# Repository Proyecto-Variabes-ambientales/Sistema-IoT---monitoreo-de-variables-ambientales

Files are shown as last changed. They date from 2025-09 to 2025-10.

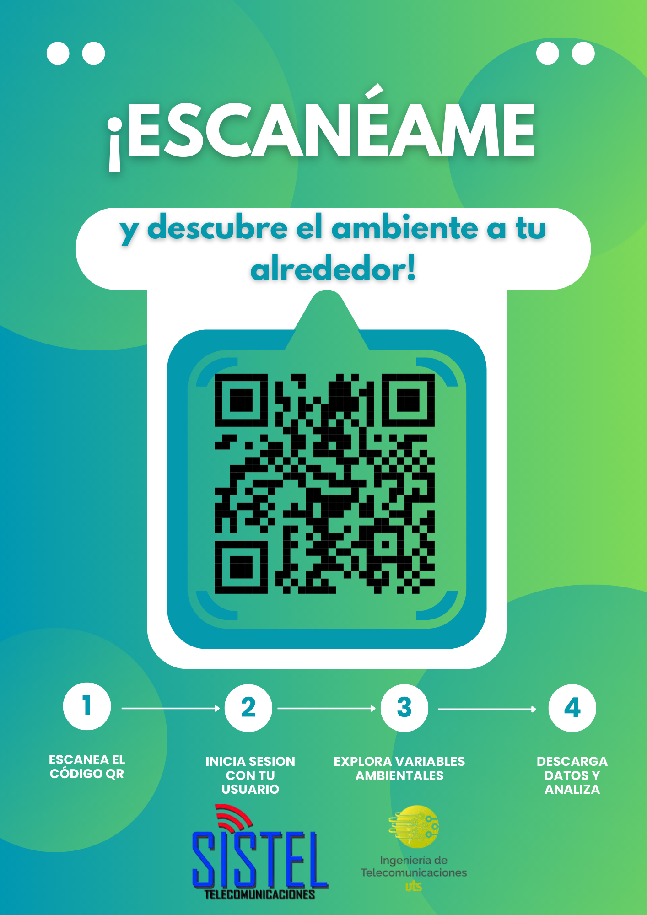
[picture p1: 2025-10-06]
Anexo F -Ficha publicitaria.png

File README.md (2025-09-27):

# Sistema-IoT---monitoreo-de-variables-ambientales
Panel web y firmware para un sistema de monitoreo de calidad del aire basado en Wemos D1 R32, con el uso de los sensores SCD40 (CO2, temperatura, humedad) y MPM10-AG (PM1.0/PM2.5/PM10). Los datos se almacenan en Firebase Realtime Database y se visualizan en un dashboard responsivo con Chart.js filtros por rango, estado y exportación a CSV

- Envío periódico de lecturas(CO2, T, RH, PM1/2.5/10).
- Gráficas en tiempo real, promedio, máx/mín, comparacion de días y fuera de rango.
- Exportación de datos a CSV por rango de fechas.
- Autentication con Firebase Auth.
- Panel admin: registro de boards con PIN por correo.
- Limites configurables y auto-referesco

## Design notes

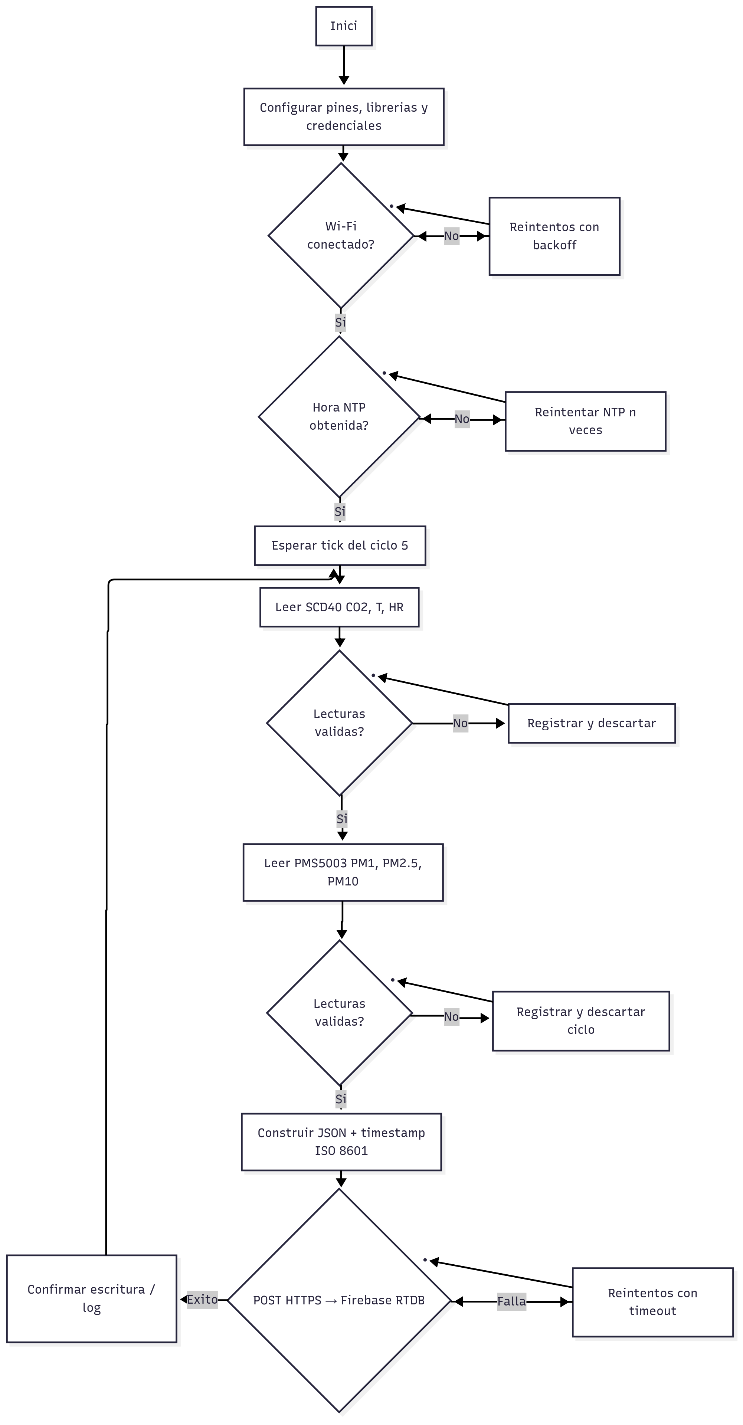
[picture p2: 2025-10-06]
Anexo E - Diagrama de flujo- Firmware.png

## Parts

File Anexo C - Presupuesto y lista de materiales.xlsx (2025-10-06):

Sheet: Materiales y precios
Cantidad | Descripción | Observación | Precio
1 | Wemos D1 R32 | Wi-Fi, 4MB flash | $45000.00
1 | SCD40 (sensor) | C02, T, RH )I2C | $95000.00
1 | MPM10-AG | PM1/2.5/10 (UART) | $52000.00
1 | Fuente 12V DC 3A | Con toma a red | $22000.00
1 | Power Bank | Bateria de respaldo | $90000.00
1 | Caja metalica | Con malla e impresiones 3D | $100000.00
8 | Cables jumper | Conectividad limpia y segura | $8500.00
4 | Tornilleria | fijacion del equipo | $10000.00
 |  |  | $422500.00

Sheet: Check-list
Checklist de instalación |  | X
Ubicación y montaje | Altura 1,7–2,0 m; zona de paso ventilada; sombra indirecta.
 | Caja fijada y nivelada; orificios de ventilación despejados y con malla.
 | Sin fuentes puntuales de calor/CO₂ a < 2 m (extractores, escapes, hornos).
Eléctrico y conexiones | Fuente 12 V ≥ 3 A; polaridad verificada.
 | Conectores bien conectados; cableado sin peladuras.
 | PMS (5 V) y SCD40 (3.3 V) con masa común.
Firmware y red | BOARD_ID programado; credenciales Wi-Fi cargadas.
 | Sincronización NTP OK; zona horaria verificada.
 | Conexión a Firebase: OK (paquetes en <5 min).
Verificación funcional (15–30 min) | Lecturas CO₂/T°/RH/PM aparecen en el dashboard.
 | Gráficas en modo tiempo real actualizan cada minuto.
 | Botones Rango/Prom/Max-Min/Comparar/Out of Range/Reset operativos.

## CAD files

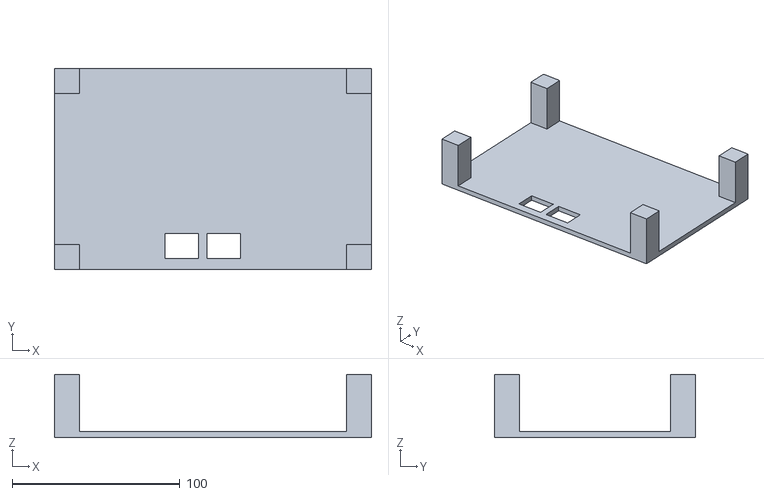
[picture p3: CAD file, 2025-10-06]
Anexo H - Diseños 3D/doble altura para bateria.stl
189.0 x 120.0 x 37.7

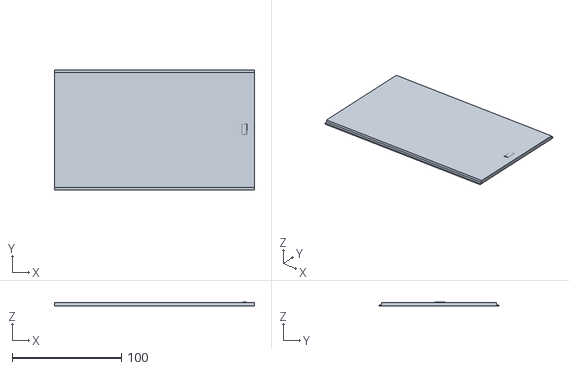
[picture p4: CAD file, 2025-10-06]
Anexo H - Diseños 3D/tapa caja principal.stl
182.7 x 109.9 x 4.03

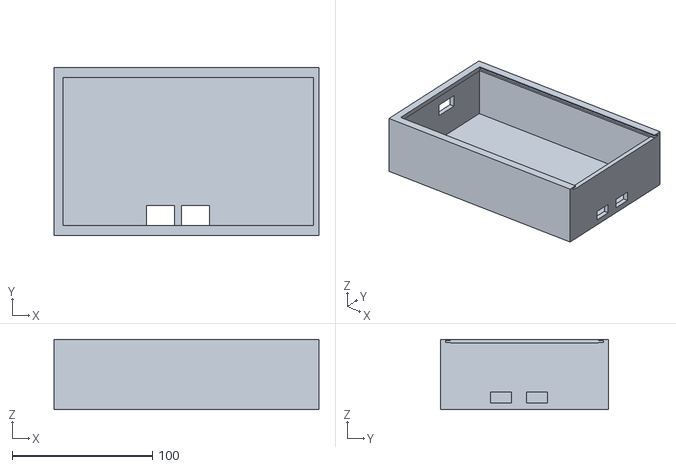
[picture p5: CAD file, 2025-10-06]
Anexo H - Diseños 3D/caja principal.stl
189.0 x 120.0 x 50.2

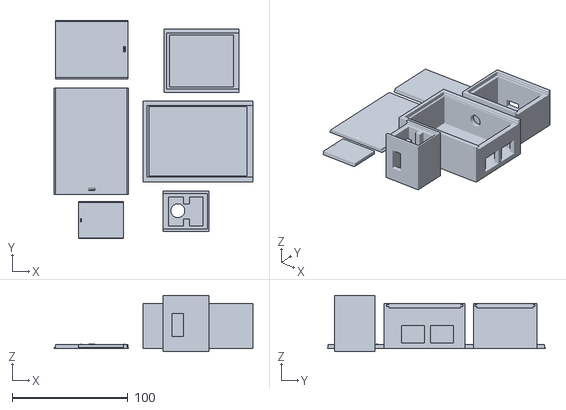
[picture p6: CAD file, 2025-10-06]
Anexo H - Diseños 3D/todas las cajas para los elementos electronicos.stl
172.0 x 188.8 x 48.5

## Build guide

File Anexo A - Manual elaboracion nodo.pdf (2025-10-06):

# Manual de construcción y

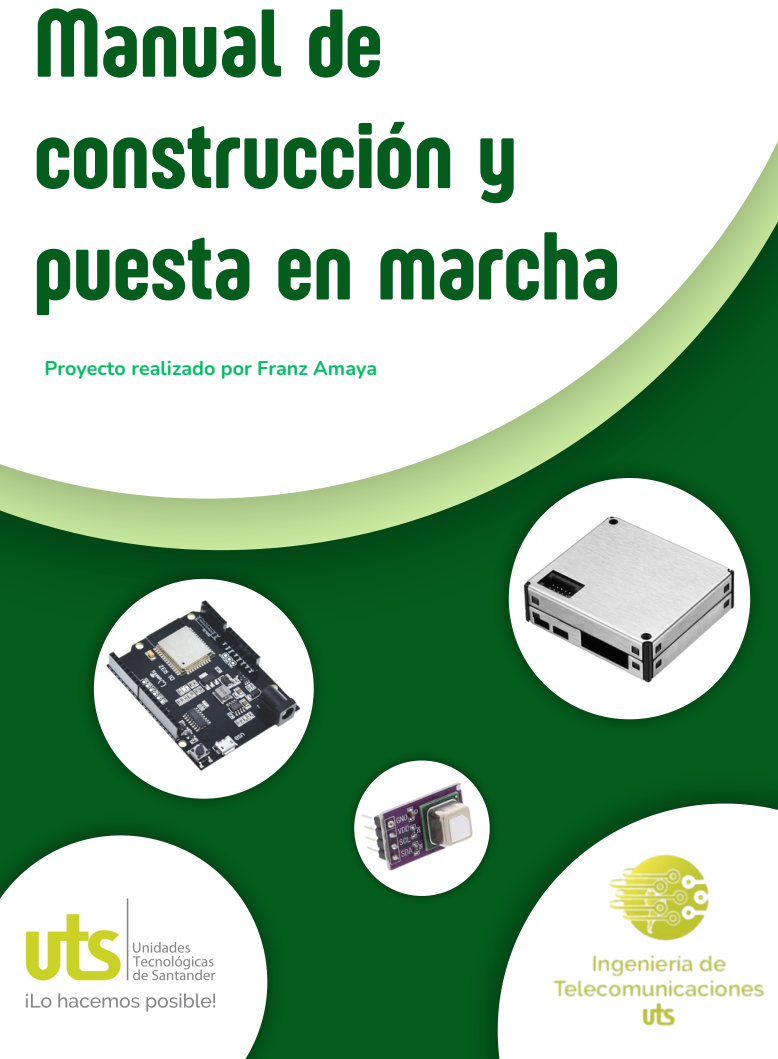
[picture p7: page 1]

puesta en marcha

Proyecto realizado por Franz Amaya

# MANUAL DE INSTRUCCIONES

Sistema IoT para el monitoreo de variables ambientales (ESP32 + SCD40 + PM2.5)

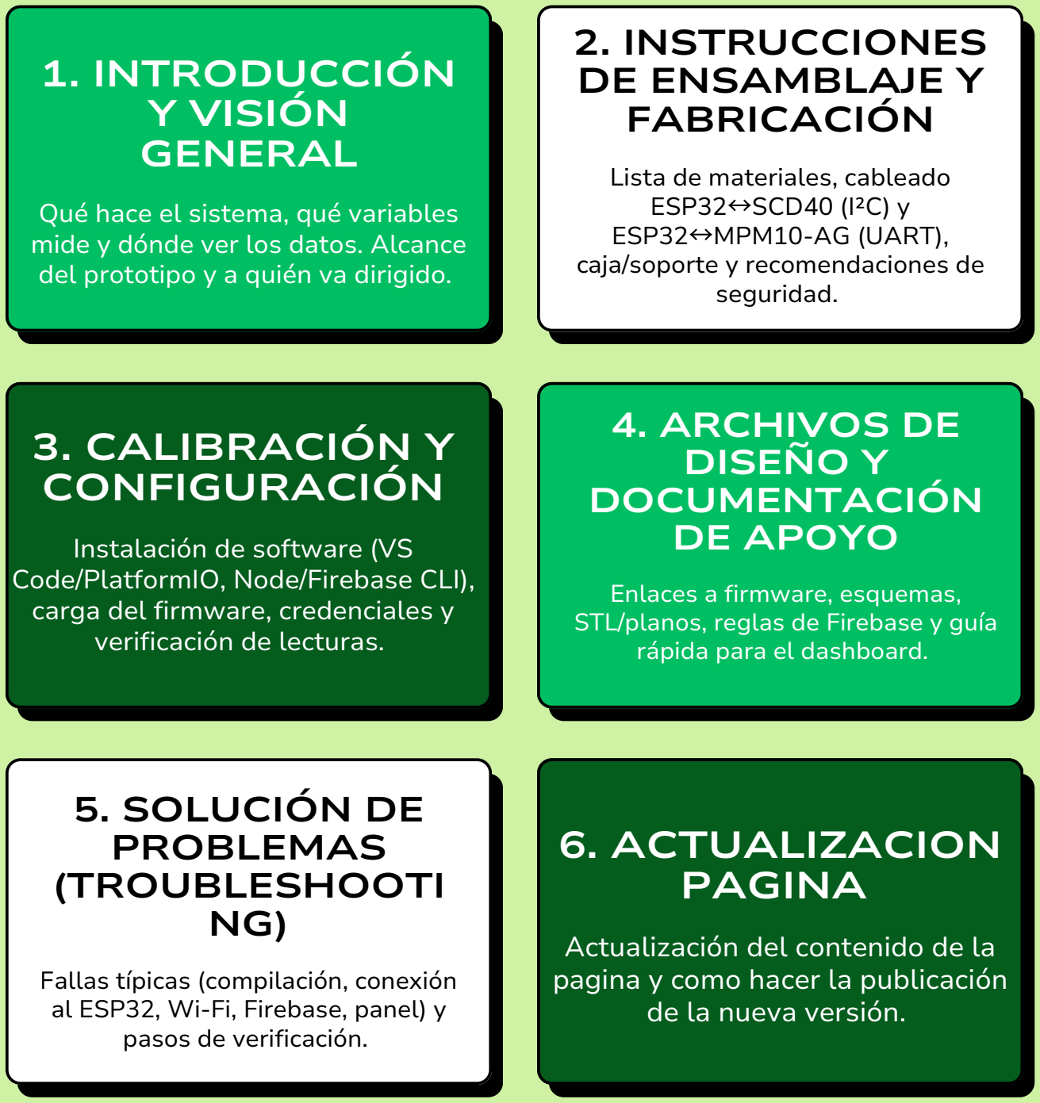
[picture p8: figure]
1. INTRODUCCIÓN Y VISIÓN GENERAL; Qué hace el sistema, qué variables mide y dónde ver los datos. Alcance del prototipo y a quién va dirigido.; 3. CALIBRACIÓN Y CONFIGURACIÓN; Instalación de software (VS Code/PlatformIO, Node/Firebase CLI), carga del firmware, credenciales y verificación de lecturas.; 5. SOLUCIÓN DE PROBLEMAS (TROUBLESHOOTI NG); Fallas típicas (compilación, conexión al ESP32, Wi-Fi, Firebase, panel) y pasos de verificación.; 2. INSTRUCCIONES DE ENSAMBLAJE Y FABRICACIÓN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

Proyecto académico – Programa Ingeniería de Telecomunicaciones – UTS.

# INSTRUCCIONES

### 1. Introducción y Visión General

### PROPÓSITO DEL MANUAL

Este manual explica paso a paso cómo reproducir el prototipo de monitoreo ambiental basado en una Wemos D1 R32 (ESP32), un sensor SCD40 (CO₂, temperatura y humedad) y un sensor láser de partículas PM2.5 (MPM10-AG). Encontrarás la lista completa de materiales, el ensamble eléctrico y mecánico, la carga del firmware, el despliegue del panel web y pruebas de verificación. La idea es que puedas copiar el proyecto de principio a fin y adaptarlo a tu contexto.

### DESCRIPCIÓN DEL PROTOTIPO

El sistema mide CO₂ (ppm), temperatura (°C), humedad relativa (%) y PM2.5 (µg/m³), sube los datos cada 5 min a Firebase Realtime Database y los muestra en un panel web con pestañas por variable, comparación por días, promedio, máximos/mínimos y aviso por colores (verde/amarillo/rojo). Se pensó para su instalación en exteriores (plazoleta UTS) con una caja protectora ventilada.

# INSTRUCCIONES

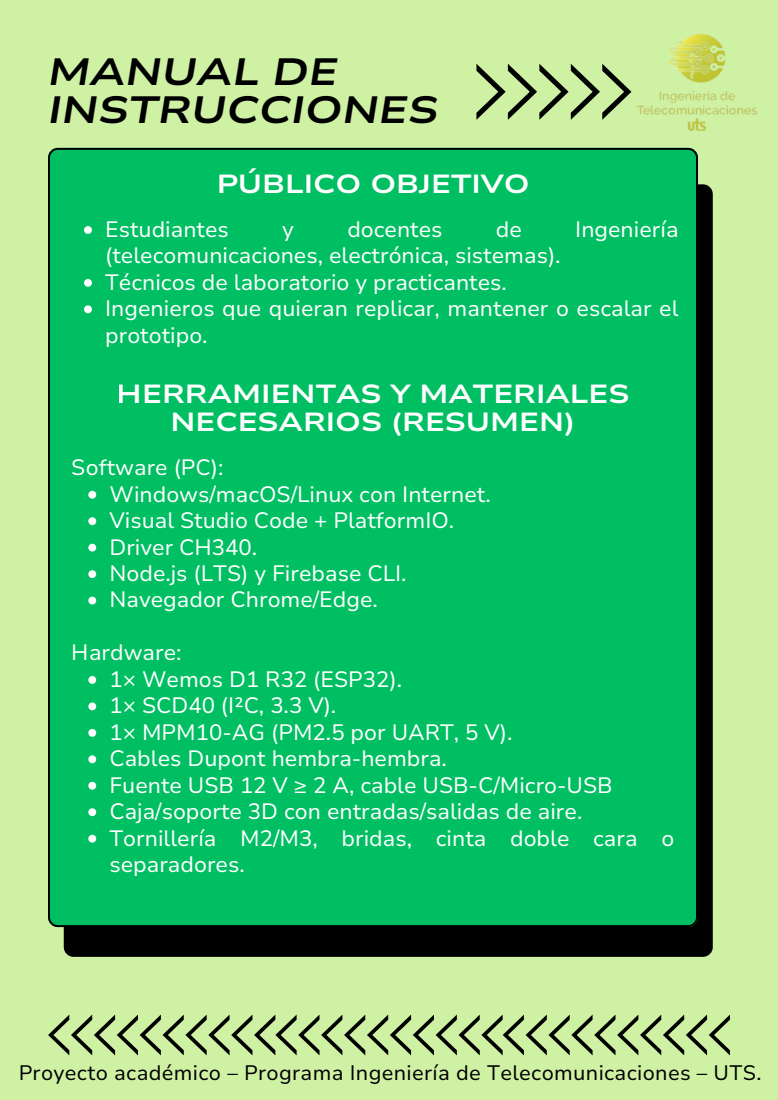
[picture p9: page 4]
PÚBLICO OBJETIVO; Estudiantes; docentes; Ingeniería

(telecomunicaciones, electrónica, sistemas).
Técnicos de laboratorio y practicantes.
Ingenieros que quieran replicar, mantener o escalar el
prototipo.
HERRAMIENTAS Y MATERIALES
NECESARIOS (RESUMEN)

Software (PC):
Windows/macOS/Linux con Internet.
Visual Studio Code + PlatformIO.
Driver CH340.
Node.js (LTS) y Firebase CLI.
Navegador Chrome/Edge.
Hardware:
1× Wemos D1 R32 (ESP32).
1× SCD40 (I²C, 3.3 V).
1× MPM10-AG (PM2.5 por UART, 5 V).
Cables Dupont hembra-hembra.
Fuente USB 12 V ≥ 2 A, cable USB-C/Micro-USB
Caja/soporte 3D con entradas/salidas de aire.
Tornillería M2/M3, bridas, cinta doble cara o
separadores.

Ítem | Cant. | Especificación
Wemos D1 R32 (ESP32) | 1 | MCU Wi-Fi/BLE a 3.3 V; USB, GPIO21=SDA, GPIO22=SCL, UART2=IO16/IO17
Sensor SCD40 | 1 | CO₂, T, RH; VCC=3.3 V, I²C (SDA/SCL)
Sensor PM2.5 MPM10-AG | 1 | Láser; VCC=5 V, UART (TX/RX)
Cables Dupont | 20+ | Hembra-hembra, 10–15 cm
Fuente USB 5 V ≥ 1A | 1 | Alimentación del ESP32
Caja/soporte | 1 | Impresa en 3D o metálica con ventilación
Tornillos/separadores | Var | M2/M3, nylon o metal
Filtros anti-insectos | 2 | Tela/fieltro respirable
PC con VSCode | 1 | PlatformIO, Firebase CLI

# INSTRUCCIONES

### 2. Instrucciones de ensamblaje y fabricación

### 2.1 LISTA DE MATERIALES (BOM)

# INSTRUCCIONES

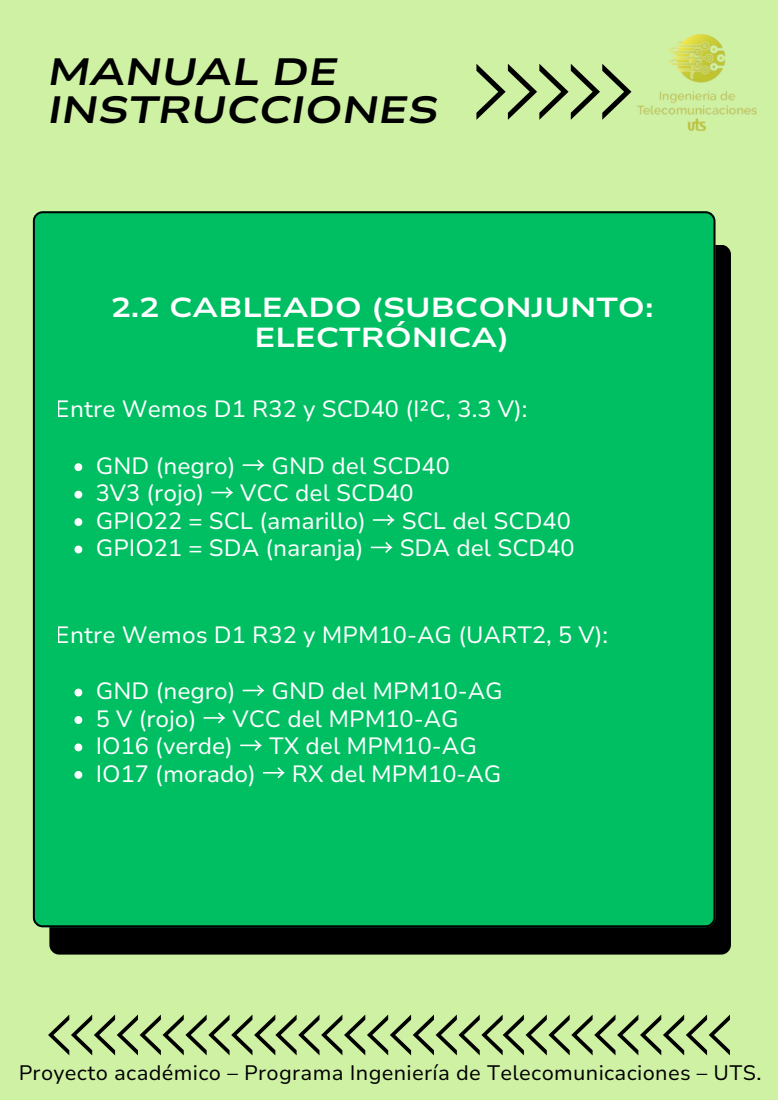
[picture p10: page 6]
2.2 CABLEADO (SUBCONJUNTO: ELECTRÓNICA)

Entre Wemos D1 R32 y SCD40 (I²C, 3.3 V):
GND (negro) → GND del SCD40
3V3 (rojo) → VCC del SCD40
GPIO22 = SCL (amarillo) → SCL del SCD40
GPIO21 = SDA (naranja) → SDA del SCD40

Entre Wemos D1 R32 y MPM10-AG (UART2, 5 V):
GND (negro) → GND del MPM10-AG
5 V (rojo) → VCC del MPM10-AG
IO16 (verde) → TX del MPM10-AG
IO17 (morado) → RX del MPM10-AG

# INSTRUCCIONES

## 2.3 CAJA/SOPORTE (SUBCONJUNTO: MECÁNICA)

Ubica el SCD40 en un compartimento ventilado y sombreado, con entrada superior tipo visera (evita radiación directa).

El PM2.5 necesita dos conductos: entrada y salida separados y alineados con sus puertos.

Deja pasajes de aire de 6–10 mm para SCD40 y conductos dedicados para el PM (30–40 mm de largo).

Mantén cables ordenados con bridas y deja juego para vibración térmica.

Considera tornillos de fijación y burletes de goma para vibración/estanqueidad.

# INSTRUCCIONES

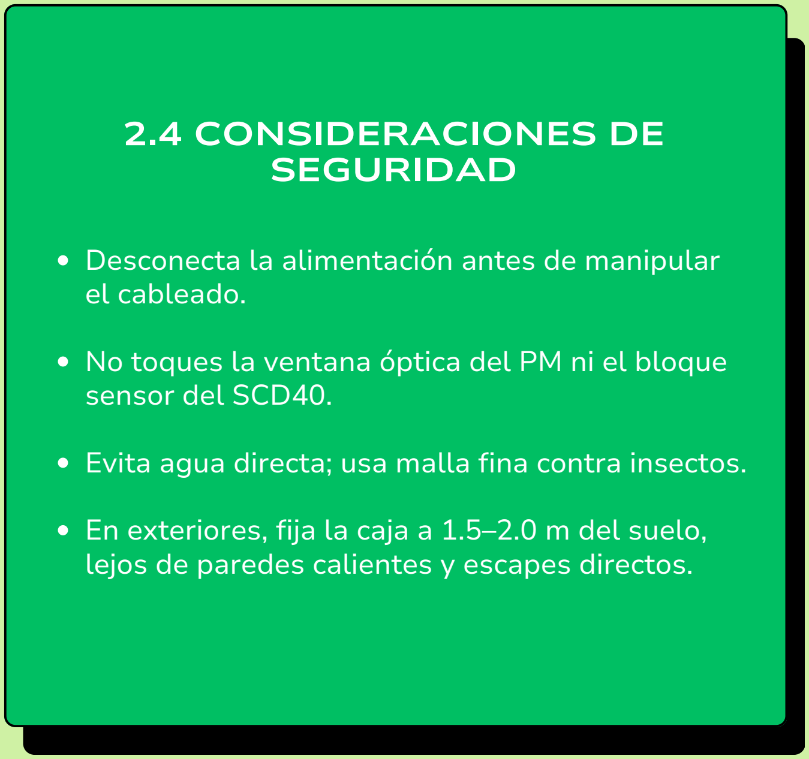
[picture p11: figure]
2.4 CONSIDERACIONES DE SEGURIDAD; el cableado.; sensor del SCD40.

Desconecta la alimentación antes de manipular

No toques la ventana óptica del PM ni el bloque

Evita agua directa; usa malla fina contra insectos.

En exteriores, fija la caja a 1.5–2.0 m del suelo, lejos de paredes calientes y escapes directos.

# INSTRUCCIONES

### 3. Calibración, software y configuración

### 3.1 INSTALACIÓN DE SOFTWARE

(PC)
1.Instala VS Code.
2.Abre VS Code → Extensions → instala PlatformIO IDE. 3.Instala driver USB (CH340).
4.Instala Node.js (LTS).
5.Abre una terminal y ejecuta:
npm i -g firebase-tools → instala Firebase CLI. firebase login → inicia sesión en tu cuenta.

### 3.2 PROYECTO PLATFORMIO

El sistema mide CO₂ (ppm), temperatura (°C), humedad relativa (%) y PM2.5 (µg/m³), sube los datos cada 5 min a Firebase Realtime Database y los muestra en un panel web con pestañas por variable, comparación por días, promedio, máximos/mínimos y aviso por colores (verde/amarillo/rojo). Se pensó para su instalación en exteriores (plazoleta UTS) con una caja protectora ventilada.

### 3.3 CODIGOS Y REGLAS

Para acceder a los códigos ingresa al siguiente GitHub y sigue el paso a paso que se describe en el README y demás archivos.

# INSTRUCCIONES

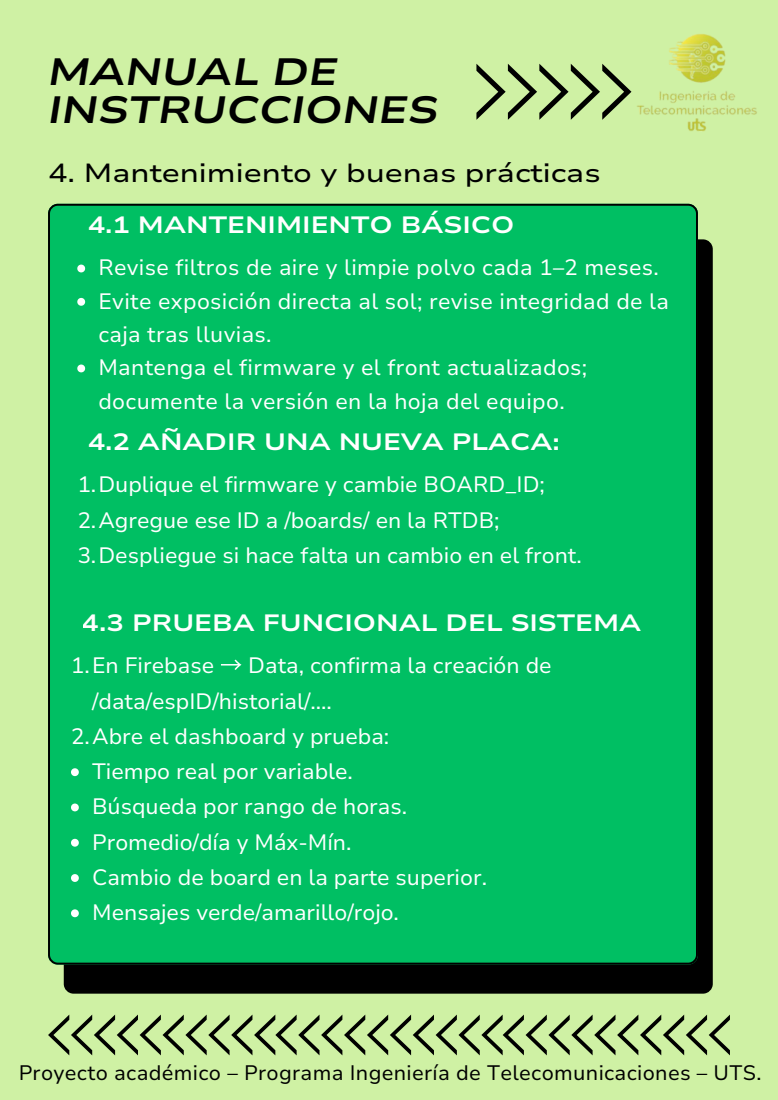
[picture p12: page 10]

4. Mantenimiento y buenas prácticas
4.1 MANTENIMIENTO BÁSICO
Revise filtros de aire y limpie polvo cada 1–2 meses.
Evite exposición directa al sol; revise integridad de la
caja tras lluvias.
Mantenga el firmware y el front actualizados;
documente la versión en la hoja del equipo.
4.2 AÑADIR UNA NUEVA PLACA:
1.Duplique el firmware y cambie BOARD_ID;
2.Agregue ese ID a /boards/ en la RTDB;
3.Despliegue si hace falta un cambio en el front.

4.3 PRUEBA FUNCIONAL DEL SISTEMA
1.En Firebase → Data, confirma la creación de
/data/espID/historial/....
2.Abre el dashboard y prueba:
Tiempo real por variable.
Búsqueda por rango de horas.
Promedio/día y Máx-Mín.
Cambio de board en la parte superior.
Mensajes verde/amarillo/rojo.

# INSTRUCCIONES

### 5. Solución de problemas (Troubleshooting)

NO COMPILA (FALTA
SENSIRIONI2CSCD4X.H)
- Agrega la librería en lib_deps o instálala desde PlatformIO → Libraries.
- Limpia el proyecto (Clean) y vuelve a compilar. “FAILED TO CONNECT TO ESP32” AL SUBIR
- Usa cable de datos.
- Presiona BOOT al iniciar la carga.
- Cambia de puerto COM.
- Instala/actualiza el driver.
NO CONECTA A WI-FI
- Solo 2.4 GHz, SSID/clave correctos (sin caracteres raros).
- Aleja la antena de cables de poder y metal.
NO APARECEN DATOS EN FIREBASE
- Revisa la URL exacta del host (…default-rtdb.firebaseio.com).
- Verifica reglas y autenticación.
- Confirma que el firmware apunte a /data/<BOARD_ID>/historial/.

# INSTRUCCIONES

EL PANEL WEB CARGA PERO NO GRAFICA
- En script.js valida BASE_URL y BOARD.
- Verifica CORS/HTTPS (usa la Hosting URL).
- Limpia caché del navegador (Ctrl+F5).
LECTURAS DE CO₂ = 0 O ERRORES DEL SCD40
- Verifica 3.3 V estable y líneas SDA/SCL (21/22).
- Evita cables >30 cm o torcidos con los de 5 V.
- Re-inicializa medición periódica en el firmware.
PM2.5 FIJA O ERRÁTICA
- Confirma 5 V al sensor y UART (IO16⇐TX, IO17⇒RX).
- Evita luz directa en el canal óptico; usa conductos/visera.
- Limpia el conducto; no uses aire comprimido directo.
- Elimina de la base de datos la lectura errónea.
EL EQUIPO DEJA DE REGISTRAR TRAS ~8 MUESTRAS
- Usa temporización con millis() (no delay largos).
- Llama http.end() siempre y evita reusar objetos entre peticiones si hay fugas.
- Re-intenta NTP y Wi-Fi si pierdes conexión.

# INSTRUCCIONES

### 6. ACTIALIZACIÓN PÁGINA WEB

- Realiza los cambios que deseas en los archivos principales y guárdalos.
- Abre la terminal en la raíz del proyecto (Es la carpeta donde está firebase.json.); en el Explorador, clic derecho dentro de esa carpeta → Open in Terminal / Abrir en PowerShell o desde el terminal de Visual Studio Code
- Despliega al hosting
En esa terminal (donde está firebase.json), ejecuta: firebase deploy --only hosting

Al terminar, verás una Hosting URL tipo https://<tu-proyecto>.web.app.

- Verifica en producción
Abre la Hosting URL y entra al login.
Si ves la versión anterior, fuerza recarga: Ctrl + F5

# INSTRUCCIONES

CIERRE
Con este manual queda operativo el prototipo que mide CO₂, temperatura, humedad y PM2.5 con ESP32, SCD40 y MPM10-AG, enviando datos a Firebase y al panel web. Registra la versión del firmware, fecha de calibración y ubicación del equipo. Si haces cambios, documenta las actualizaciones y conserva copias de los archivos de diseño.

Para soporte, escribe al correo: proyectouts22@gmail.com

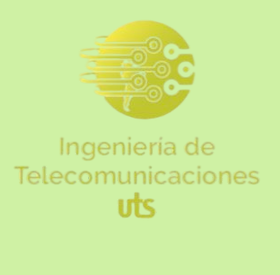
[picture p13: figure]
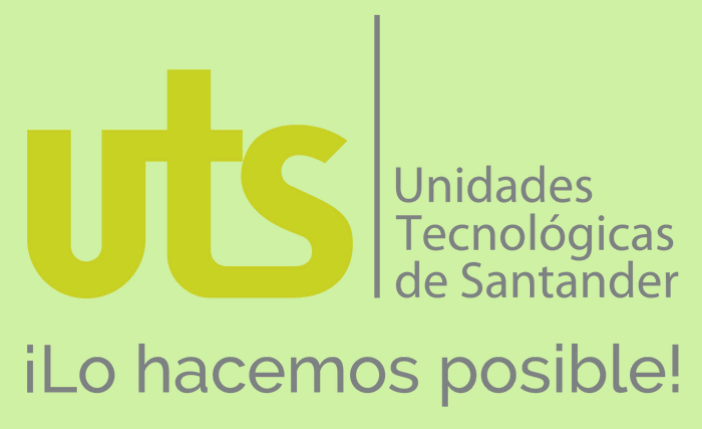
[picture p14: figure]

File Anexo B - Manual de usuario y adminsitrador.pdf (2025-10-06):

# Manual de Usuario -Manual de

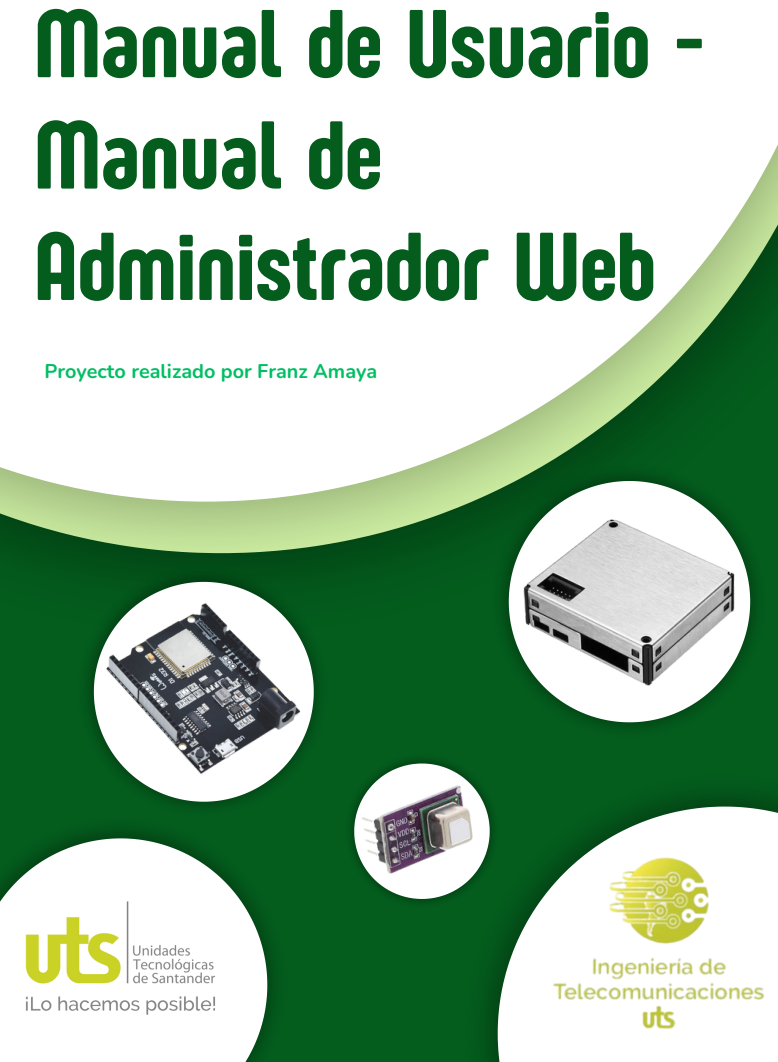
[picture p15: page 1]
Administrador Web

Proyecto realizado por Franz Amaya

# MANUAL DE USUARIO

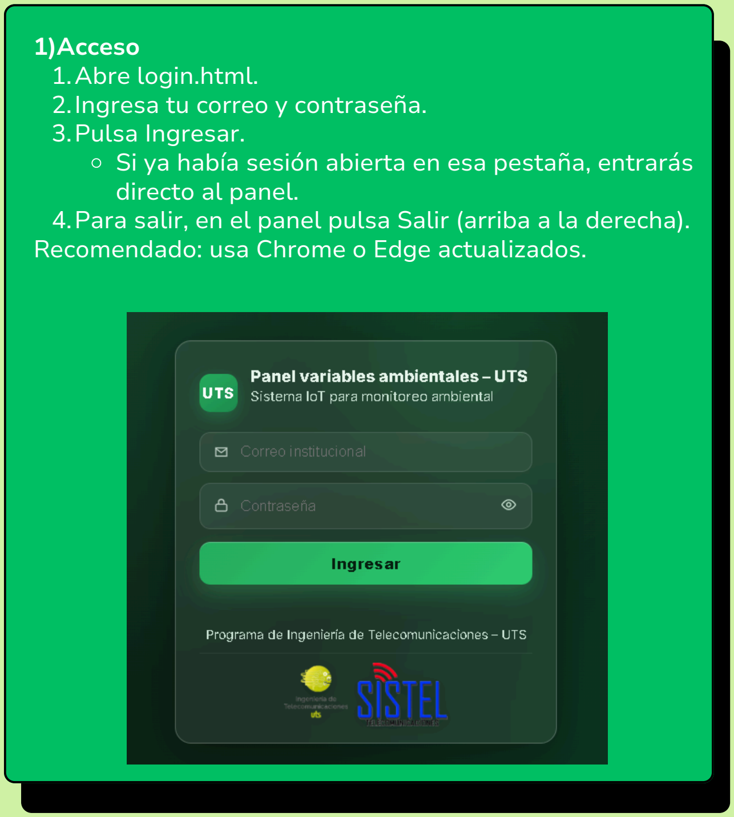
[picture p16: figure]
1)Acceso 1.Abre login.html. 2.Ingresa tu correo y contraseña. 3.Pulsa Ingresar.; directo al panel.

Si ya había sesión abierta en esa pestaña, entrarás

4.Para salir, en el panel pulsa Salir (arriba a la derecha). Recomendado: usa Chrome o Edge actualizados.

Proyecto académico – Programa Ingeniería de Telecomunicaciones – UTS.

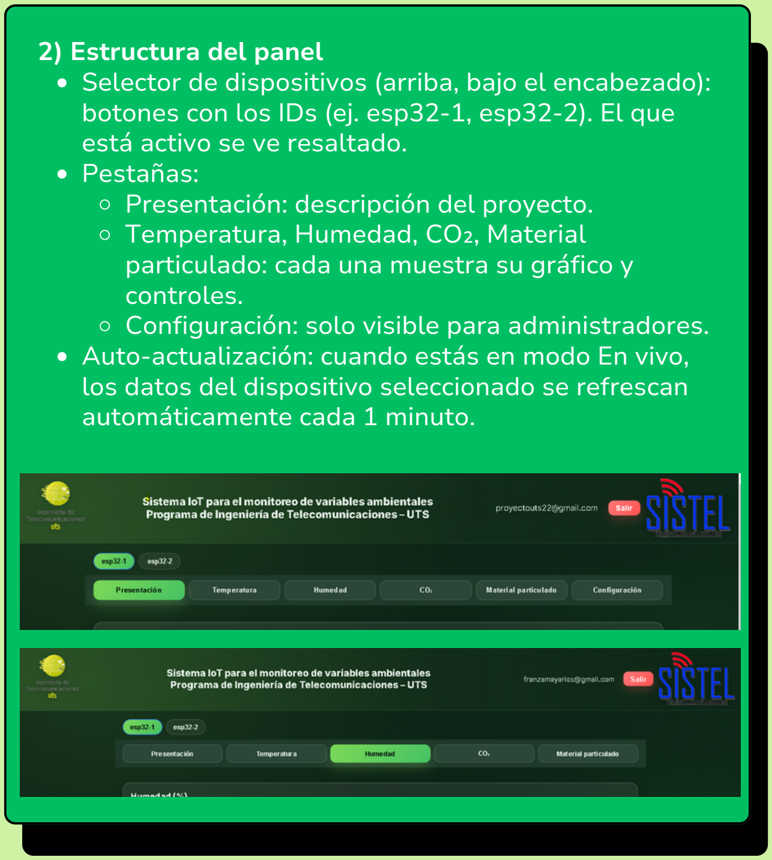
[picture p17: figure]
2) Estructura del panel; está activo se ve resaltado. Pestañas: Presentación: descripción del proyecto. Temperatura, Humedad, CO₂, Material; controles. Configuración: solo visible para administradores.; automáticamente cada 1 minuto.

Selector de dispositivos (arriba, bajo el encabezado): botones con los IDs (ej. esp32-1, esp32-2). El que

particulado: cada una muestra su gráfico y

Auto-actualización: cuando estás en modo En vivo, los datos del dispositivo seleccionado se refrescan

# USUARIO

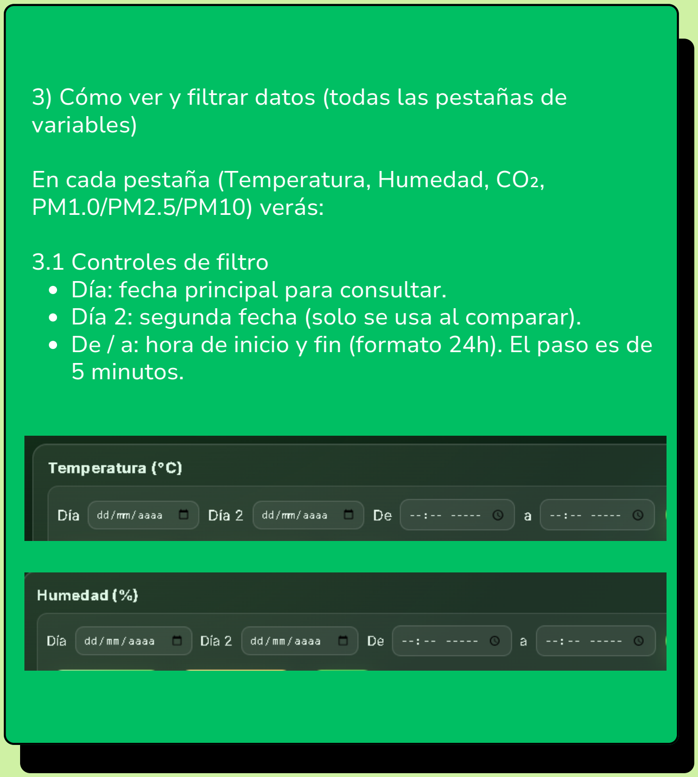
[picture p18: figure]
variables); PM1.0/PM2.5/PM10) verás:; 3.1 Controles de filtro Día: fecha principal para consultar.; 5 minutos.

3) Cómo ver y filtrar datos (todas las pestañas de

En cada pestaña (Temperatura, Humedad, CO₂,

Día 2: segunda fecha (solo se usa al comparar).
De / a: hora de inicio y fin (formato 24h). El paso es de

# USUARIO

Botones de acción:
Rango: grafica todas las muestras del Día entre la hora De y a.
Promedio: calcula y grafica el promedio del Día seleccionado.
Máx/Mín:
Si seleccionas Día, muestra los valores mínimo y máximo de ese día.
Si no pones fecha, calcula mínimo y máximo históricos del dispositivo actual.
Comparar días: requiere Día, Día 2 y horas De / a. Grafica las dos series en el mismo eje para comparar.
Fuera de rango: lista solo las muestras por debajo del mínimo o por encima del máximo definidos para la variable.
En vivo: limpia filtros (borra los inputs) y vuelve al tiempo real con actualización automática.
Nota: si limpias todos los campos (o pulsas En vivo), la pestaña vuelve al modo tiempo real.

# USUARIO

# USUARIO

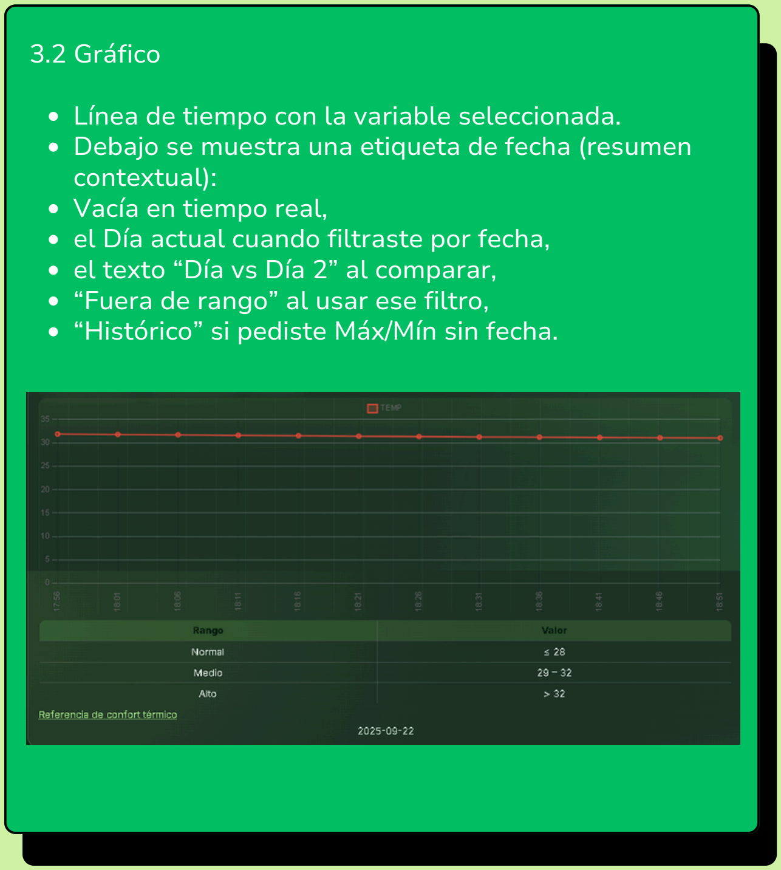
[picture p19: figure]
3.2 Gráfico; contextual): Vacía en tiempo real,; el texto “Día vs Día 2” al comparar, “Fuera de rango” al usar ese filtro,

Línea de tiempo con la variable seleccionada. Debajo se muestra una etiqueta de fecha (resumen

el Día actual cuando filtraste por fecha,

“Histórico” si pediste Máx/Mín sin fecha.

# USUARIO

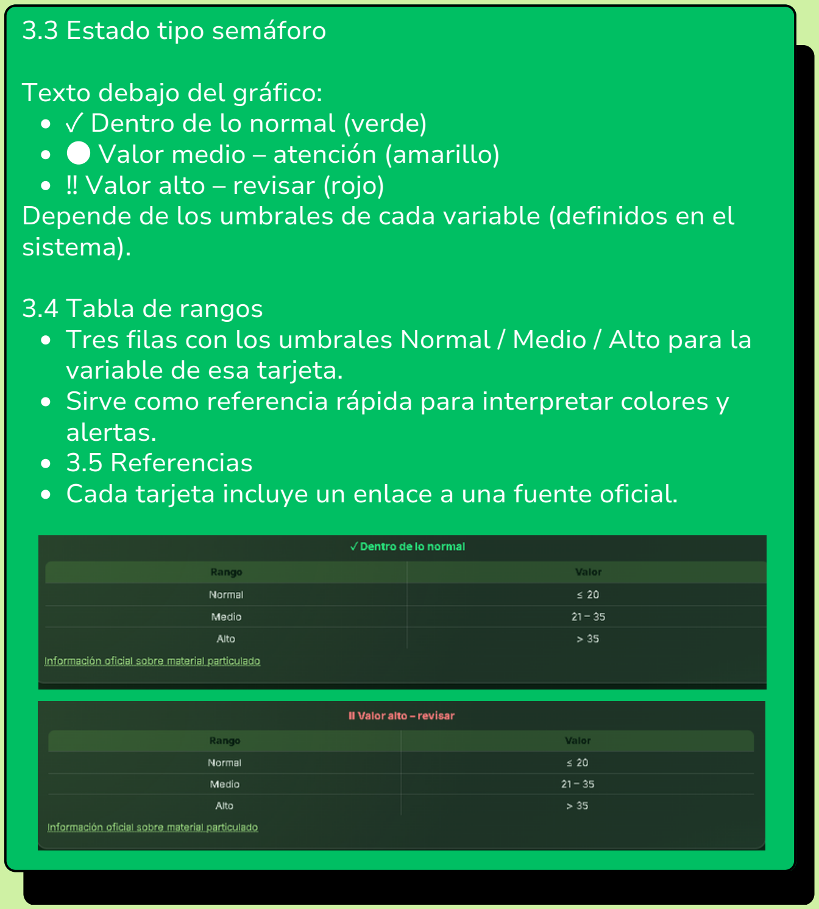
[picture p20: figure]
3.3 Estado tipo semáforo; Texto debajo del gráfico: ✓ Dentro de lo normal (verde) ● Valor medio – atención (amarillo) ‼ Valor alto – revisar (rojo); sistema).; 3.4 Tabla de rangos; variable de esa tarjeta.; alertas. 3.5 Referencias

Depende de los umbrales de cada variable (definidos en el

Tres filas con los umbrales Normal / Medio / Alto para la

Sirve como referencia rápida para interpretar colores y

Cada tarjeta incluye un enlace a una fuente oficial.

# ADMINISTRADOR

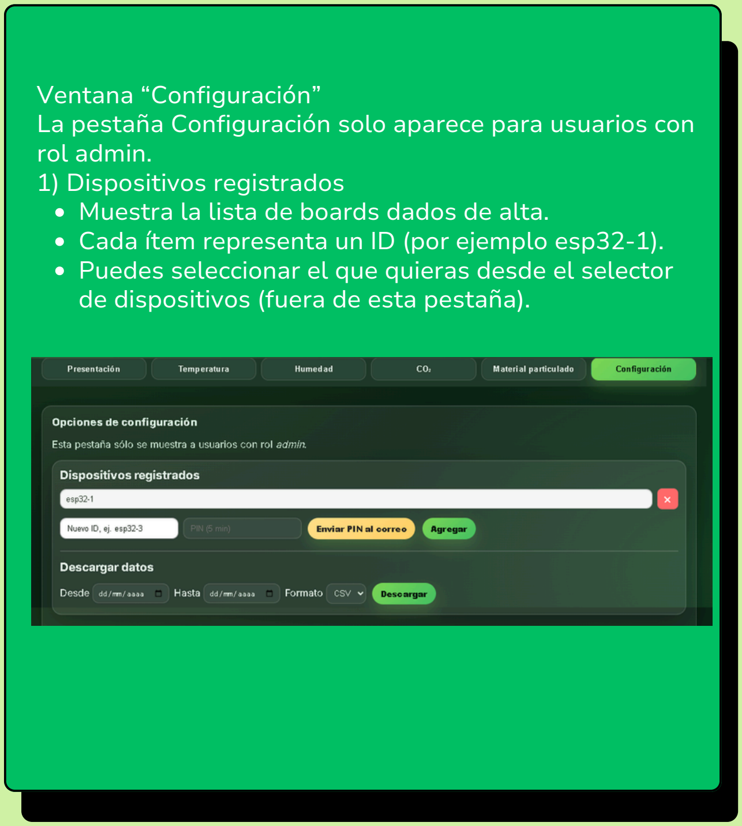
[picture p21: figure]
Ventana “Configuración”; rol admin. 1) Dispositivos registrados

La pestaña Configuración solo aparece para usuarios con

Muestra la lista de boards dados de alta.
Cada ítem representa un ID (por ejemplo esp32-1). Puedes seleccionar el que quieras desde el selector de dispositivos (fuera de esta pestaña).

1.1 Agregar un nuevo dispositivo (alta de board) 1.En “Dispositivos registrados”

, escribe el ID nuevo (ej. esp32-3) en el campo Nuevo ID.
Solo letras, números o guiones ([A-Za-z0-9-]). 2.Pide un PIN de verificación: Pulsa Enviar PIN al correo.
El sistema genera un PIN de 6 dígitos, lo guarda en Firebase por 5 min y lo envía al correo configurado del admin.
3.Revisa el correo, copia el PIN y pégalo en PIN (5 min). 4.Pulsa Agregar.
Si el PIN es válido y vigente, el board queda registrado y listo para usarse.
5.El nuevo ID aparecerá en la lista y también en el selector de dispositivos del panel.
Seguridad: el PIN se marca como usado tras un alta correcta; si expira (5 min), debes solicitar uno nuevo.

# ADMINISTRADOR

# ADMINISTRADOR

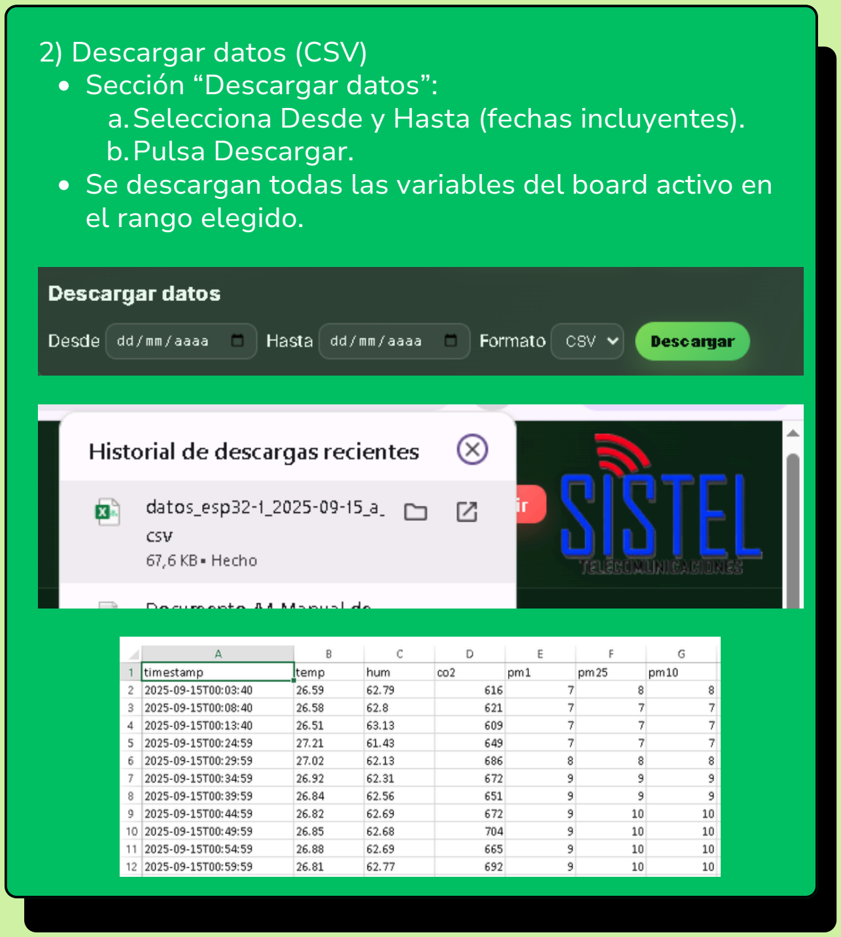
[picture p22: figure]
2) Descargar datos (CSV) Sección “Descargar datos”:; b.Pulsa Descargar.; el rango elegido.

a.Selecciona Desde y Hasta (fechas incluyentes).

Se descargan todas las variables del board activo en
